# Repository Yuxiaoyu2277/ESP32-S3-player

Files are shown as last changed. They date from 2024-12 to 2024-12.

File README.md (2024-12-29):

# 时光磁带（ESP32 S3 MP3播放器）
- Description
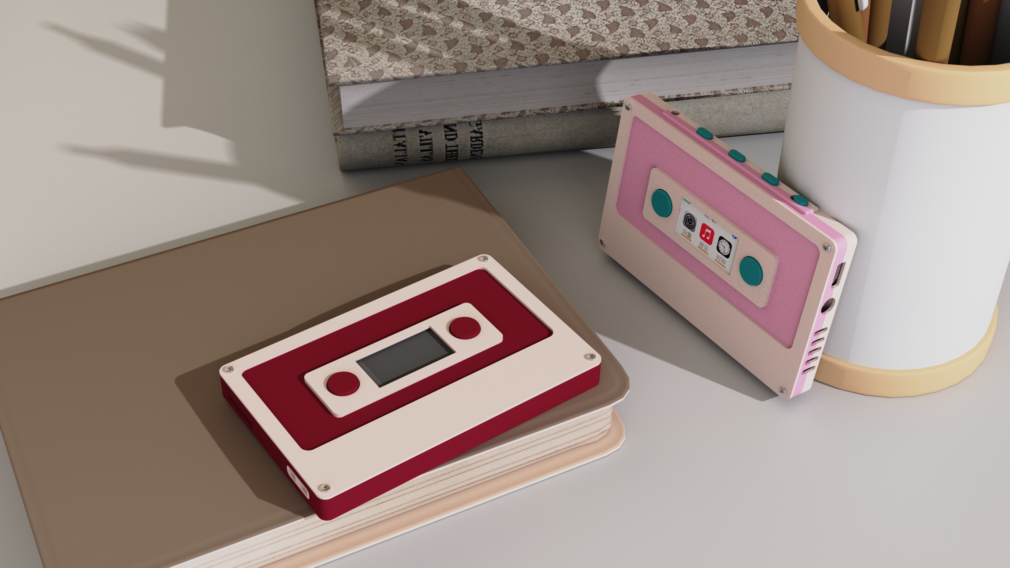
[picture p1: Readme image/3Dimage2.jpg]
- 
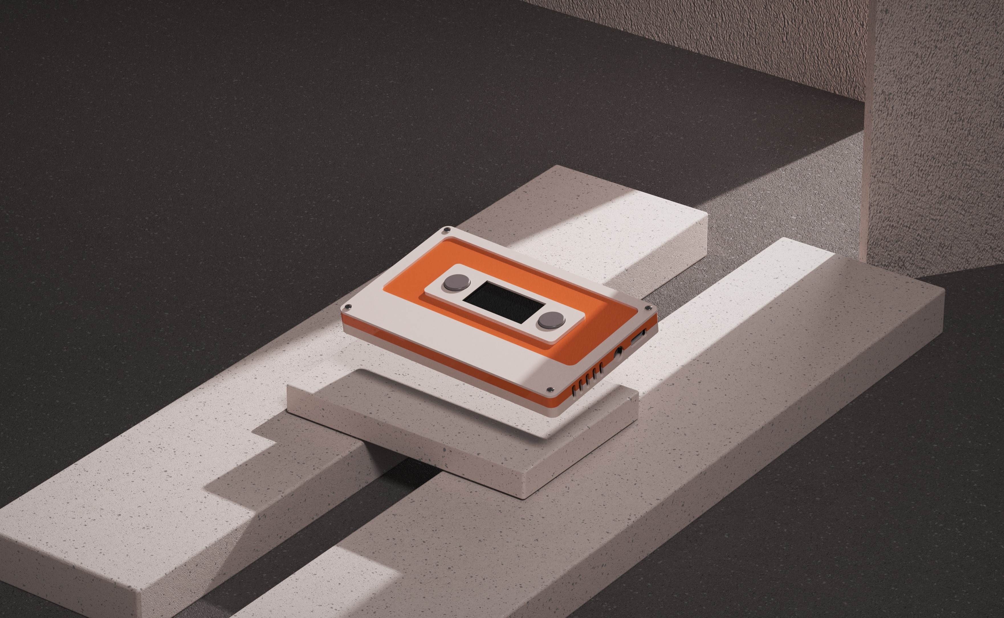
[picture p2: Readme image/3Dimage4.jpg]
- 

# [中文版](README.md) / [English Version](README.en.md)
## 目录
- [概述](#概述)
- [特性](#特性)
- [硬件型号](#硬件型号)
- [原理图](#原理图)
- [如何编译软件部分](#如何编译软件部分)
- [固件](#固件)
- [代码](#代码)
- [贡献](#贡献)
- [联系](#联系)
## 概述
本项目是一个提供硬件及软件的指南，用于构建基于ESP32 S3微控制器的MP3播放器。该设备拥有磁带复古外形的外壳，具备音乐播放、时间显示。

## 特性
该MP3播放器基于ESP32 S3微控制器，集成了2.4 GHz Wi-Fi和蓝牙5 (LE)，配备1.14英寸TFT LCD屏幕显示界面、BM8563 RTC芯片离线时间功能、WM8978 DAC高保真音频输出、NS4150B功率放大器增强音质、ETA6002充电芯片支持快速充电，同时支持USB Type-C充电和数据传输、SD/TF卡扩展存储（最高32G）、3.5mm耳机插孔以及高品质超薄扬声器，满足多样化的音乐播放需求。
## 硬件型号
- ESP32 S3：主要处理单元，集成Wi-Fi和蓝牙。
- TFT LCD（1.14英寸）：显示模块，用于用户界面。
- BM8563 RTC：实时时钟芯片，用于离线时间。
- WM8978 DAC：音频转换芯片，用于高保真声音。
- NS4150B PA：功率放大器芯片，用于音频输出。
- ETA6002 充电：锂电池充电芯片，用于锂电池充电。
- USB Type-C端口：用于充电和数据传输。
- SD/TF卡读卡器：用于存储扩展。
- 耳机插孔：3.5mm音频输出。
- 扬声器：提供音频播放。
- 按钮：具有5个按钮对UI进行交互控制。
- 开关：拥有1个开关控制电源开启关闭。

## 原理图 
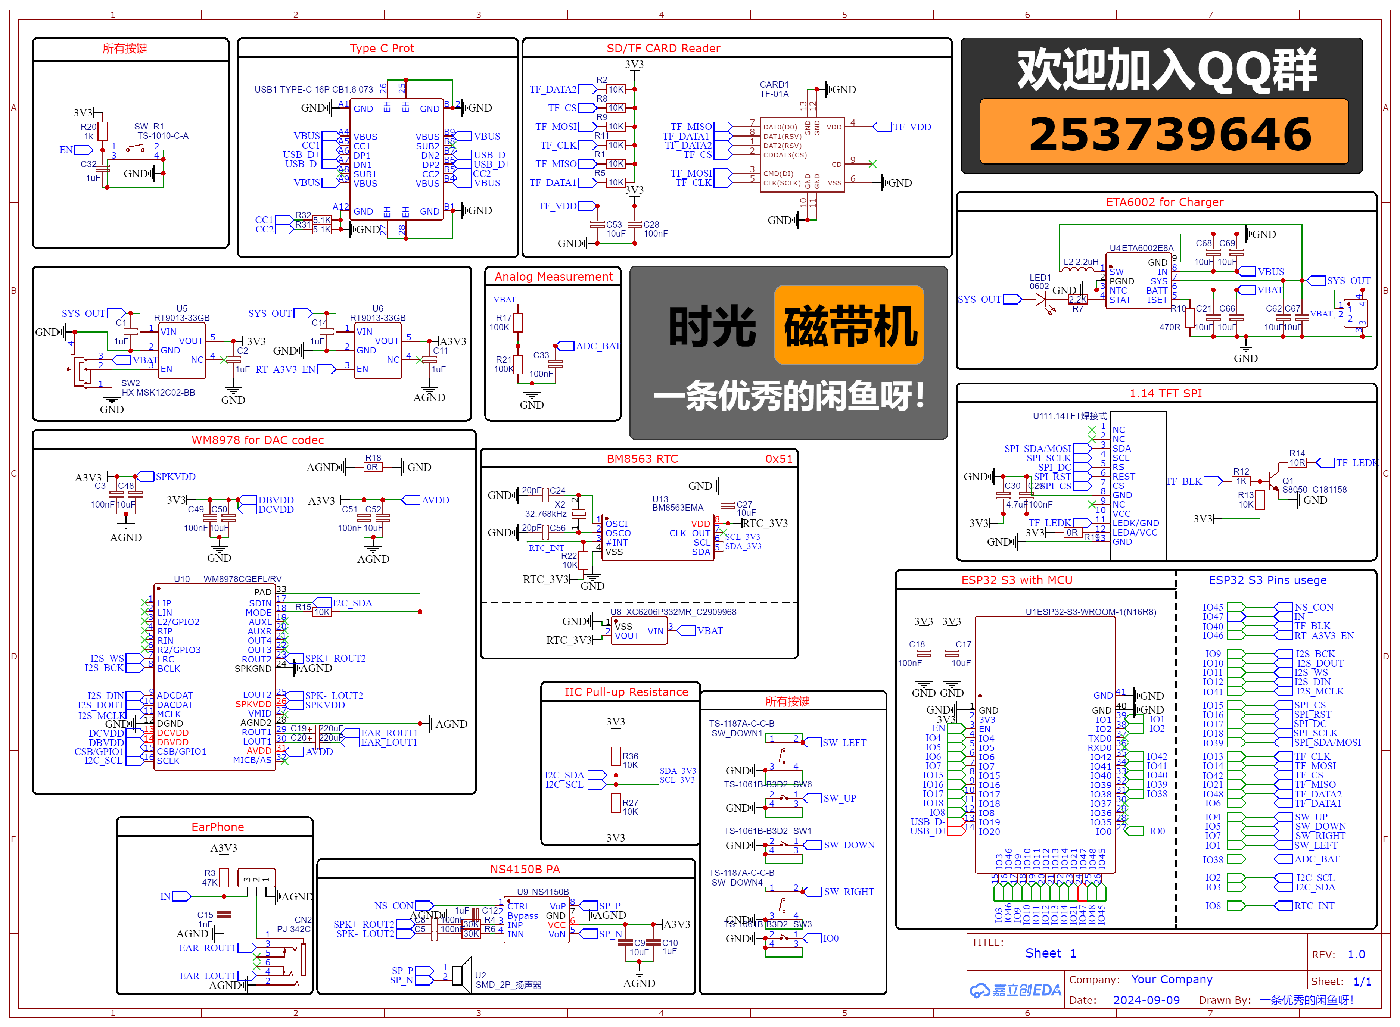
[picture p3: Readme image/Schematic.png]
- 
### 主要原理图解析
- **复位按钮**：EN引脚是ESP32 S3核心的复位引脚，采用按钮形式下拉接地该引脚可复位。按钮增加电容和电阻是为了去除电平毛刺，避免出现错误复位。
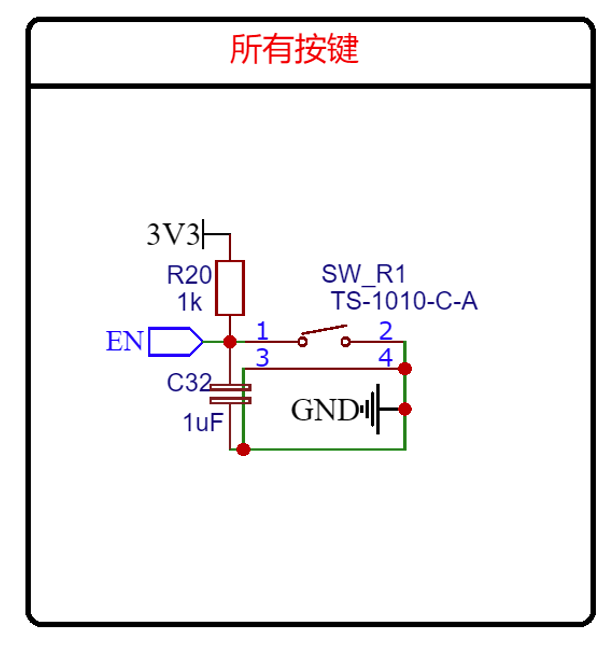
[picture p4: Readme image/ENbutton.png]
  > 
- **操作按钮**：IO_0为ESP32 S3的切换下载模式的功能按钮也可以是作为GUI操作反馈，其他按钮为GUI操作反馈。
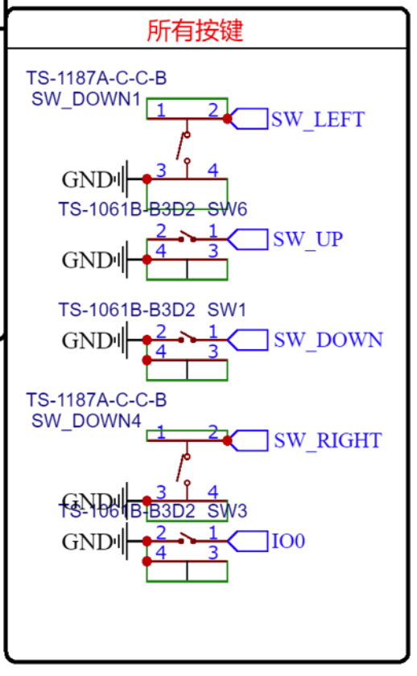
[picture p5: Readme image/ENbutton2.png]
  > 
- ESP32 S3 引脚分配表:
> 核心MCU接线说明：
> 如图所示，这是引脚的分配，核心有两个滤波电容靠近核心，是为了过滤电源线的干扰，保证核心供电稳定。其中引脚分配如下：

| **引脚编号** | **功能描述** | **备注** |
|---|---|---|
| IO45 | NS_CON | 对NS4150B的音频输出是否静音进行控制（高电平为允许声音输出）|
| IO47 | IN | 检测3.5MM耳机是否插入，如插入就是低电平 |
| IO40 | TF_BLK | 通过PWM信号进行控制屏幕亮度 |
| IO46 | RT_A3V3_EN | 音频的电压稳定芯片的开关（上拉给予3V3电压为开启） |
| IO9 | I2S_BCK | 音频接口（I2S）位时钟线 |
| IO10 | I2S_WS | 音频接口（I2S）音频左右声数据切换|
| IO11 | I2S_DOUT | 音频接口（I2S）WM8978芯片数据至ESP32 S3|
| IO12 | I2S_DIN | 音频接口（I2S）数据至WN8978芯片 |
| IO41 | I2S_MCLK | 音频接口（I2S）额外频率时钟参考线线|
| IO15 | SPI_CS | SPI接口 |
| IO16 | SPI_RST | SPI接口 |
| IO17 | SPI_DC | SPI接口 |
| IO18 | SPI_SCLK | SPI接口 |
| IO39 | SPI_SDA/MOSI | SPI接口 |
| IO13 | TF_CLK | TF卡/SD接口 |
| IO14 | TF_MOSI | TF/SD卡接口 |
| IO7 | TF_CS | TF/SD卡接口 |
| IO48 | TF_DATA2 | TF/SD卡接口 |
| IO2 | TF_DATA1 | TF/SD卡接口 |
| IO21 | SW_UP | 按键 |
| IO20 | SW_DOWN | 按键 |
| IO19 | SW_RIGHT | 按键 |
| IO8 | SW_LEFT | 按键 |
| IO0 | IO0 | 按键/切换下载模式 |
| IO4 | ADC_BAT | 电池电量检测 |
| IO2 | I2C_SCL | I2C接口 |
| IO3 | I2C_SDA | I2C接口 |
| IO8 | RTC_INT | 实时时钟中断接口 |
| IO19 | USB_D- | USB数据/type C物理接口连接 |
| IO20 | USB_D+ | USB数据/type C物理接口连接 |
- 其中仍然未用到的引脚有TXD0、RXD0原本是用于调试接口；但因为ESP32 S3支持USB日志调试，因此烧录固件可以不用单独的自动下载电路来进行烧录固件。其次关于IO37、IO36、IO35为芯片flash引脚所占用的，所以为了谨慎起见不进行使用。如果想要了解更多，请参考乐鑫官方的ESP32 S3数据手册，有你想知道的一切！
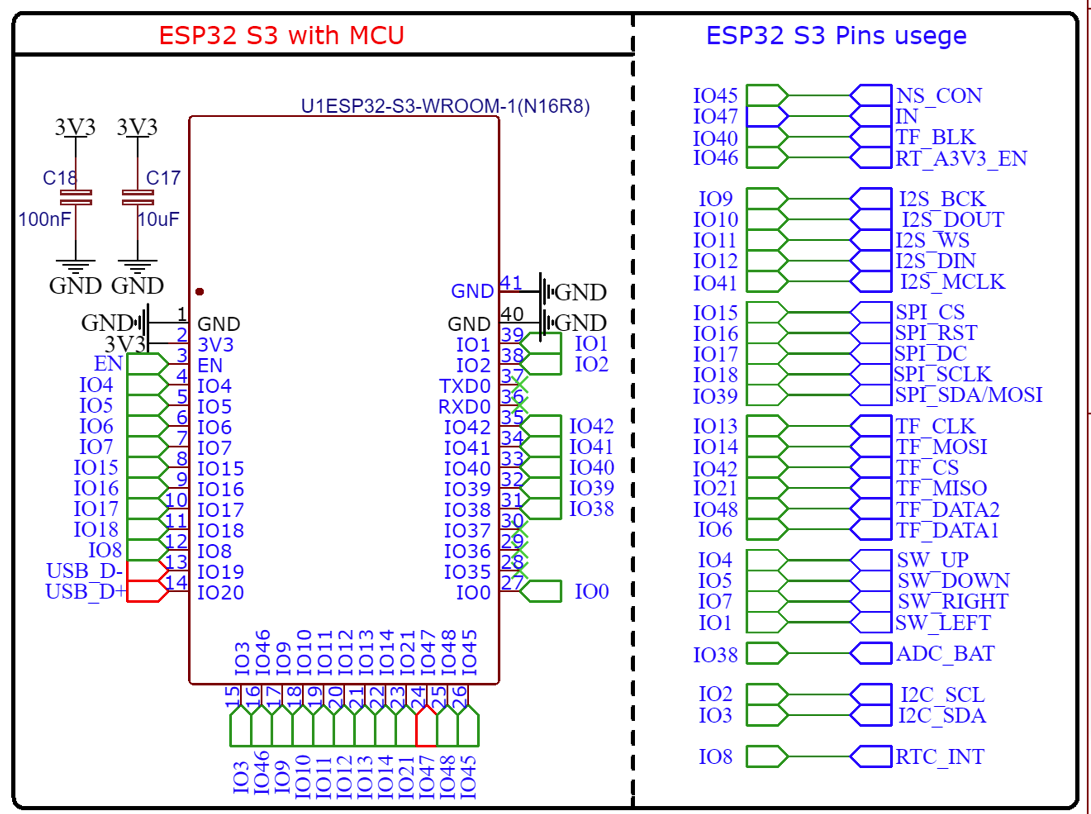
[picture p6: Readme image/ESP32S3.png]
> 
- **WM8978 DAC**: A3V3 是提供给模拟电路部分的电源。通过 C48（100nF）和 C3（10uF）电容进行滤波，3V3 为数字部分供电，通过 C49 和 C50（100nF 和 10uF）进行滤波，SPKVDD 为扬声器供电，通过 C19 和 C20（220uF）进行电源滤波。
 I2C_SCL 和 I2C_SDA 引脚（引脚 16 和 17）通过 I2C 接口控制 WM8978 的配置，EAR_LOUT1 和 EAR_ROUT1 是左右声道的耳机输出引脚，他们经过钽电容输出到耳机接口（注意建议使用钽电容，假如因为成本可以换成陶瓷电容）。SPK+ 和 SPK- 是扬声器的输出引脚，支持单声道扬声器，分别通过 AGND 接地，构成差分驱动的扬声器信号。
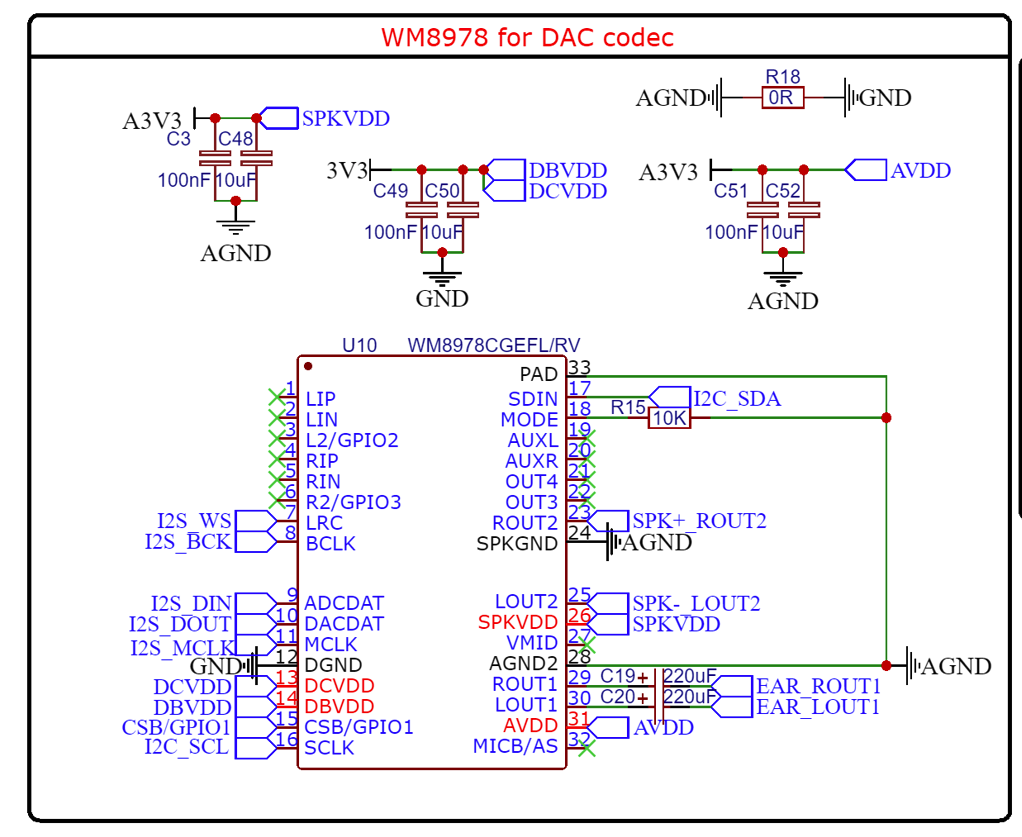
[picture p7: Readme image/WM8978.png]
> 
- **NS4150B和3.5MM**：该部分电路为音频放大器以及3.5MM接口电路，在3.5MM接口上R3、C15为滤波和限流是为了上拉该引脚的电平，当有耳机插入时耳机的线路会把引脚接地，这样就可以检测是否有耳机插入。当插入时就可以切换音频输出的模式。注意：IN检测电路部分我使用了一个切换焊盘，这个切换焊盘用于测试用途，默认需要把2-3点连接，可采用0R电阻进行连接。在NS4150B芯片上NS_CON为音频输出是否静音进行控制（高电平为允许声音输出），芯片的3号4号引脚是DAC的模拟音频输入，8号和5号是放大后的音频输出
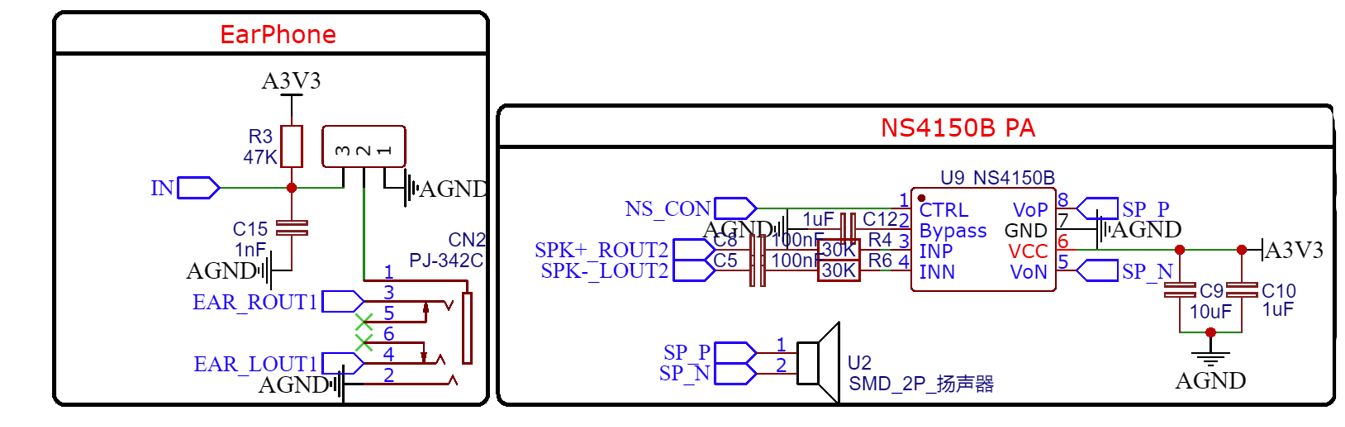
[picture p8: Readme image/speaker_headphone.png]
> 
- **BM8563**：RTC模块通过一个32.768kHz的晶振器提供时钟信号，并通过I2C接口与主控制器通信。RTC模块的电源引脚通过一个10uF的电容进行滤波，而地引脚接地。XC6206P332MR电源管理芯片负责为主RTC模块供电，它从电池（VBAT）获取电源并通过内部稳压器输出稳定的RTC_3V3电压。INT引脚为中断引脚，如果该引脚被拉低，就会触发ESP32 S3的中断，用于定时任务策略。整个设计中，多个接地电容用于稳定电源和减少噪声，确保RTC模块能在主电源断开时继续运行。
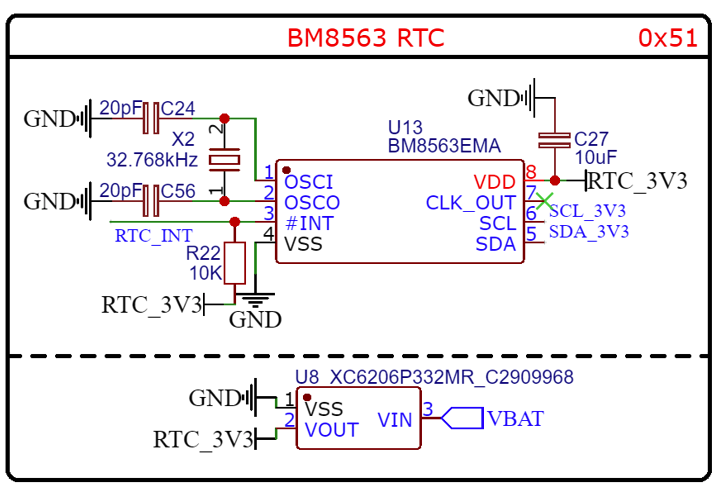
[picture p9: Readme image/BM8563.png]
> 
- **TF/SD 卡**:该电路图是一个SD/TF卡电路，通过10kΩ上拉电阻将TF_DATA2、TF_CS、TF_MOSI、TF_MISO、TF_DATA1和TF_CLK等信号线连接到3.3V电源，确保信号传输稳定。所有信号线引出后，使用者可以使用SDIO模式或者SPI模式访问储存卡。
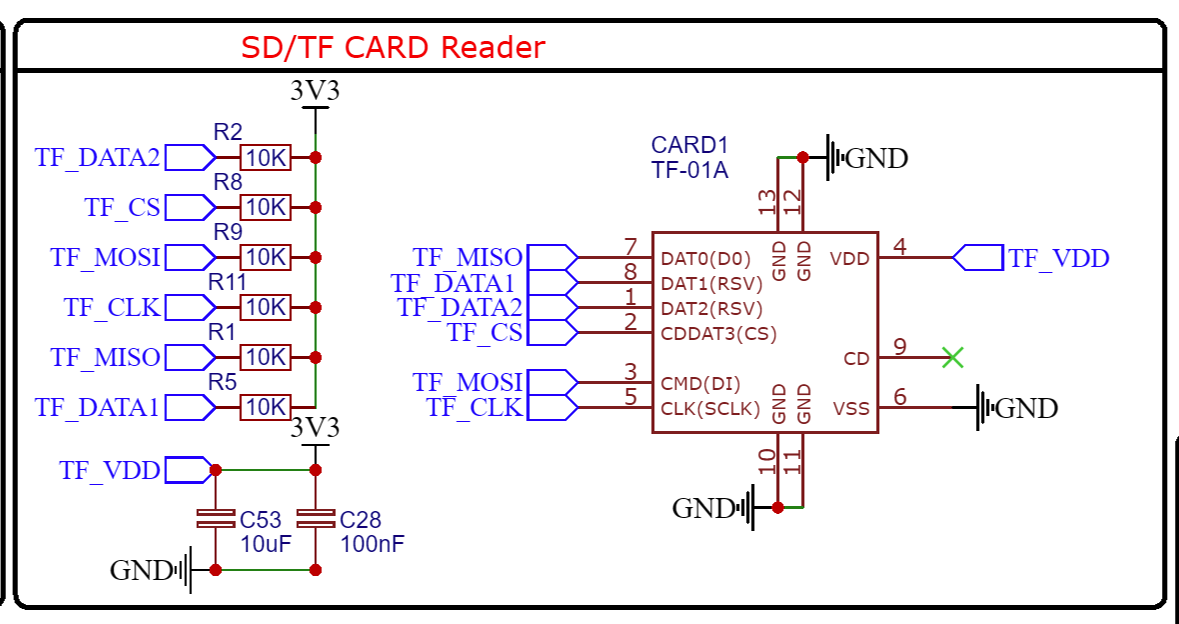
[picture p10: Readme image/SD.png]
> 
- **ETA6002**:电路通过VBUS引脚接收USB电源输入，并利用电容进行滤波和稳定。SW引脚通过2.2uH电感和2.2k电阻控制充电芯片的开关操作。VBAT引脚连接到电池正极同时VBAT会利用ADC进行监测电池电压判断电量。SYS_OUT引脚提供稳定的系统输出电压给LDO，除此之外LED和2.2k电阻指示充电状态。NTC引脚用于热管理（但因为不用所以直接接地），ISET引脚通过470电阻设置充电电流（2A）。
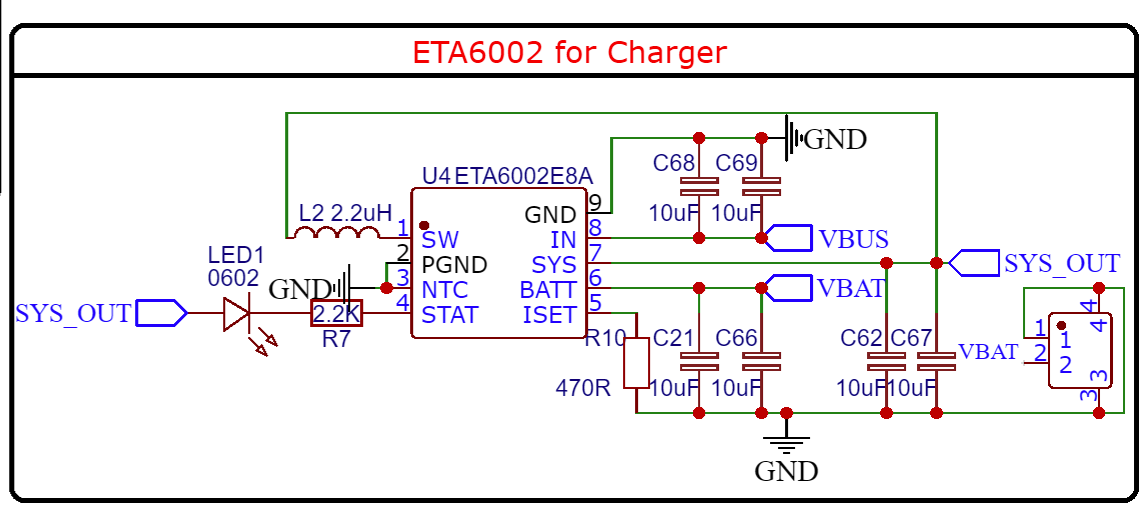
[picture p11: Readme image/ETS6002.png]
> 
## 如何开始硬件部分
- 本项目的PCB设计文件在Schematic内，里面提供了PCB的制版文件，可以通过**嘉立创**进行制作你的电路板。
- 除此之外在Schematic内提供ibom的HTML页面，方便您进行购买相关元器件。
### PCB模型预览

### 硬件部分注意事项
暂无（等候补充）
## 如何编译软件部分
- 本项目使用**Arduino IDE 2.3.4**版本进行编译，确保使用乐鑫官方的SDK版本为**2.0.14**（注意因为3.0.X版本会让工程编译产生未知的错误，为了避免请下载安装对应的SDK版本）
- 开发板的flash容量的分配16M Flash (6.25M APP/6.25MB LittleFS)，因此需要自行修改，具体修改需要对Arduino安装目录进行删除和修改文件，这里提供方法：
> 打开文件路径
```
C:\Users\（你的windows账户用户名）\AppData\Roaming\arduino-ide\Local Storage\leveldb
```
- 把关于.ldb格式文件进行删除，例如：000062.ldb（编号是随机的，你并不一定是这个文件名，只需要看文件格式进行删除）
> 打开文件路径
```
C:\Users\（你的windows账户用户名）\AppData\Local\Arduino15\packages\esp32\hardware\esp32\2.0.14
```
- 打开boards.txt文件，寻找esp32s3.menu.PartitionScheme关键字信息，并在末尾添加并保存
```boards.txt
esp32s3.menu.PartitionScheme.myMP3=MP3 16M Flash (6.25M APP/6.25MB LittleFS)
esp32s3.menu.PartitionScheme.myMP3.build.partitions=big
esp32s3.menu.PartitionScheme.myMP3.upload.maximum_size=6553600
```
> 打开文件路径
```
C:\Users\你的windows账户用户名）\AppData\Local\Arduino15\packages\esp32\hardware\esp32\2.0.14\tools\partitions
```
- 新建添加big.csv文件，并写入以下内容为flash的分区进行配置
```plaintext
# Name,   Type, SubType, Offset,  Size, Flags
nvs,      data, nvs,     0x9000,  0x5000,
otadata,  data, ota,     0xe000,  0x2000,
app0,     app,  ota_0,   0x10000, 0x640000,
app1,     app,  ota_1,   0x650000,0x640000,
spiffs,   data, spiffs,  0xc9000,0x360000,
coredump, data, coredump,0xFF0000,0x10000,
```
### 开发板配置信息

| 项目 | 详情 |
|---|---|
| 开发板 | ESP32S3 Dev Module |
| 端口 | COM4 |
| USB CDC On Boot | Enabled |
| CPU Frequency | 240MHz (WiFi) |
| Core Debug Level | None |
| USB DFU On Boot | Disabled |
| Erase All Flash Before Sketch Upload | Disabled |
| Events Run On | Core 1 |
| Flash Mode | QIO 80MHz |
| Flash Size | 16MB (128Mb) |
| JTAG Adapter | Integrated USB JTAG |
| Arduino Runs On | Core 1 |
| USB Firmware MSC On Boot | Disabled |
| Partition Scheme | MP3 16M Flash (6.25M APP/6.25MB LittleFS) |
| PSRAM | OPI PSRAM |
| Upload Mode | UART0 / Hardware CDC |
| Upload Speed | 921600 |
| USB Mode | Hardware CDC and JTAG |
| 编程器 | Esptool |

### Arduino IDE 和 SDK 版本信息

| 项目 | 详情 |
|---|---|
| Arduino IDE 版本 | 2.3.4 |
| SDK 版本 | 2.0.14 |

### 进行编译
确保编译环境一致之后，请下载GitHub本项目中的src文件夹，里面的library是所需的第三方库，这些第三方库我都进行了修改，因此和原生的第三方库都不会进行兼容。按照开源协议，我需要把自己更改的库开放出来，并注明出处。
- 打开文件路径
```text
C:\Users\（你的windows账户用户名）\Documents\Arduino\libraries
```
- 把本项目的libraries复制到你所打开本地的文件路径（注意如果本地文件路径相同名字相同的话，请在复制粘贴之前先删除本地文件路径相同的第三方库，避免造成冲突与不兼容）
- 最后请下载GitHub本项目中的ESP32_MP3_PLAYER文件夹，打开**ESP32_MP3_PLAYER.ino**，点击上传编译到板子
- 如果发生编译错误，请通过联系的联系方式告知我！使用QQ联系维护者2277236944或发送Email至Oliver.yuchunto@gmail.com
## 固件
本项目的固件是开源的，可以在本仓库的主分支中找到。为.bin格式文件，请自行google怎么直接烧录固件。
## 代码
## 贡献
欢迎贡献！如果您发现任何问题或有改进建议，请提出问题或提交拉取请求。或者直接联系我进行沟通。
## 许可证
本项目根据GNU通用公共许可证协议，只要您遵守许可证的条款，就可以自由使用、修改和分发代码，但出处必须！必须！必须！注明本项目guthub来源网址链接或注明作者：一条优秀的闲鱼呀！

## 联系
> 如有任何问题或咨询
- **推荐加入QQ群聊**：253739646
- **个人QQ**：2277236944
- **发送Email**：Oliver.yuchunto@gmail.com

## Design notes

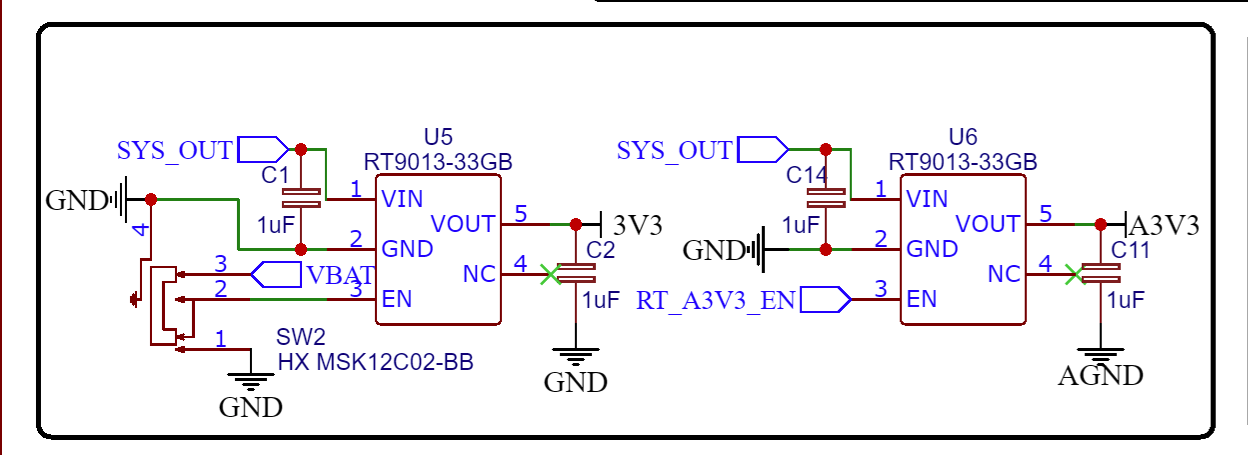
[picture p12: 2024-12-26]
Readme image/LDO.png

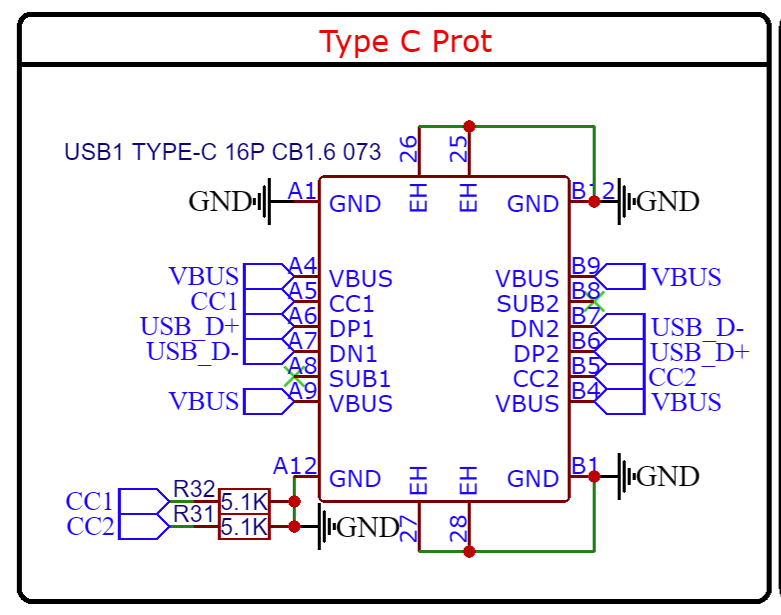
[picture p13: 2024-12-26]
Readme image/typeC.png

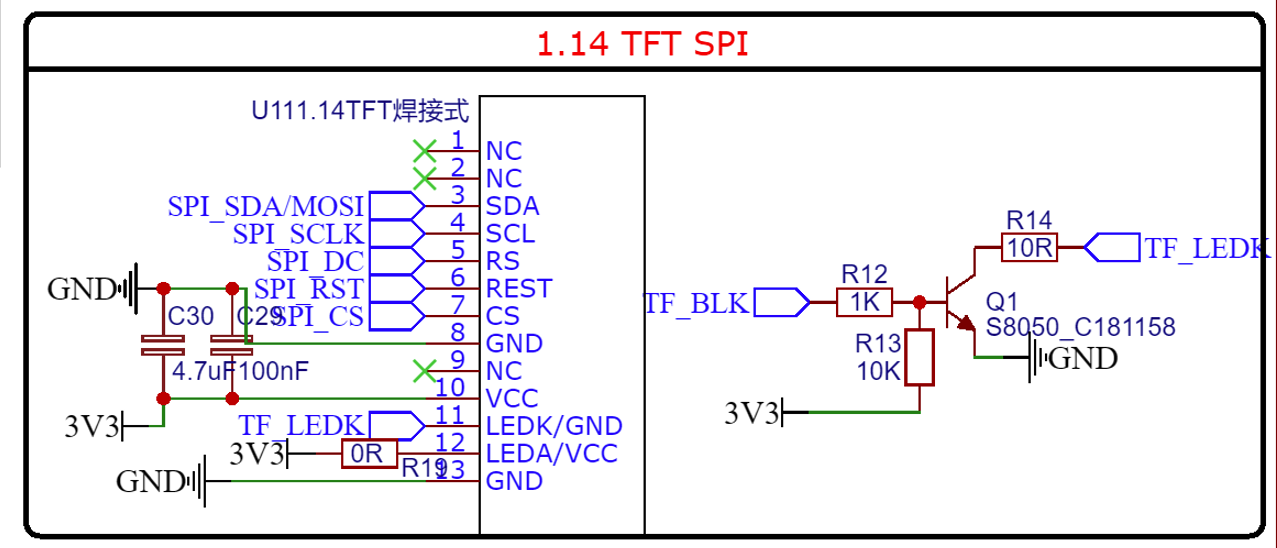
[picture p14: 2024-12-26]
Readme image/1.14.png

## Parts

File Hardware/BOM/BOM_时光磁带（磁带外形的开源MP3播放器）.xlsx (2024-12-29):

ID | Name | Designator | Footprint | Quantity
1 | 100nF | C3,C49,C51,C29,C33,C5,C8,C18,C28 | C0603 | 9
2 | 220uF | C19,C20 |  | 2
3 | 10uF | C48,C50,C52,C9,C17,C21,C53,C62,C66,C67,C68,C69,C27 | C0603 | 13
4 | 10K | R15,R1,R2,R5,R8,R9,R11 | R0603 | 7
5 | WM8978CGEFL/RV | U10 | WQFN-32_L5.0-W5.0-P0.50-TL-EP | 1
6 | NS4150B | U9 | NS4150 | 1
7 | 100K | R17 | R0603 | 1
8 | 10R | R14 | R0603 | 1
9 | 10K | R22,R27,R36,R13 | R0603 | 4
10 | TF-01A | CARD1 | TF-SMD_TF-01A | 1
11 | 4.7uF | C30 | C0603 | 1
12 | 0R | R19,R18 | C0603 | 2
13 | 100K | R21 | R0603 | 1
14 | 1uF | C1,C2,C10,C11,C12,C14,C32 | C0603 | 7
15 | 1nF | C15 | C0603 | 1
16 | 470R | R10 | C0603 | 1
17 | PJ-342C | CN2 | AUDIO-SMD_PJ-342C | 1
18 | Header-Male-2.54_1x3 | H4 | JMP-3-NO-0603 | 1
19 | 2.2uH | L2 | IND-SMD_L4.4-W4.2 | 1
20 | 0602 | LED1 | LED-SMD_L1.6-W1.0_TZ-P2-0602RTIS2-1.0T | 1
21 | S8050_C181158 | Q1 | SOT-23-3_L2.9-W1.6-P1.90-LS2.8-BR | 1
22 | 47K | R3 | R0603 | 1
23 | 30K | R4,R6 | R0603 | 2
24 | 2.2K | R7 | R0603 | 1
25 | 1k | R20 | R0603 | 1
26 | 5.1K | R31,R32 | R0603 | 2
27 | HX MSK12C02-BB | SW2 | SW-SMD_MSK12C02-HB | 1
28 | TS-1010-C-A | SW_R1 | KEY-SMD_TX-1010-X-X | 1
29 | ESP32-S3-WROOM-1(N16R8) | U1 | WIRELM-SMD_ESP32-S3-WROOM-1U-无散热孔 | 1
30 | SMD_2P_扬声器 | U2 | SMD_2P_扬声器 | 1
31 | ETA6002E8A | U4 | ESOP-8_L4.9-W3.9-P1.27-LS6.0-BL-EP-1 | 1
32 | RT9013-33GB | U5,U6 | SOT-23-5_L3.0-W1.7-P0.95-LS2.8-BL | 2
33 | TYPE-C 16P CB1.6 073 | USB1 | USB-C-SMD_SHOU_TYPE-C-16P-CB1.6 | 1
34 | TS-1061B-B3D2 | SW1,SW3,SW6 | KEY-SMD_TS-1061B-B3D2 | 3
35 | 1K | R12 | R0603 | 1
36 | 20pF | C24,C56 | C0603 | 2
37 | XC6206P332MR_C2909968 | U8 | SOT-23-3_L2.9-W1.3-P0.95-LS2.4-BR | 1
38 | 32.768kHz | X2 | CRYSTAL-SMD_L3.2-W1.5 | 1
39 | BM8563EMA | U13 | MSOP-8_L3.0-W3.0-P0.65-LS5.0-BL | 1
40 | 1.14TFT焊接式 | U11 | 1.14TFT焊接式B | 1
41 | TS-1187A-C-C-B | SW_DOWN1,SW_DOWN4 | SW-SMD_4P-L5.1-W5.1-P3.70-LS6.5-TL-2 | 2

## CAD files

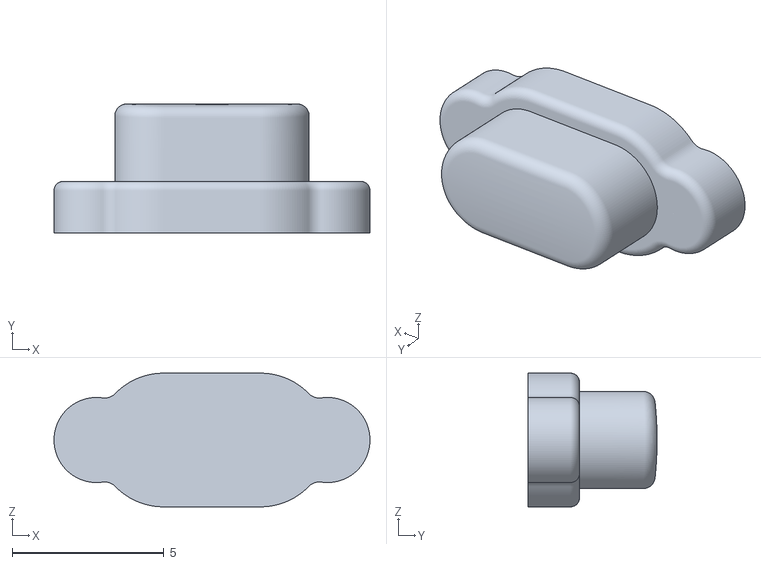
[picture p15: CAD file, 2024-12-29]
Modles/上侧边按钮1.stl
10.4 x 4.25 x 4.40

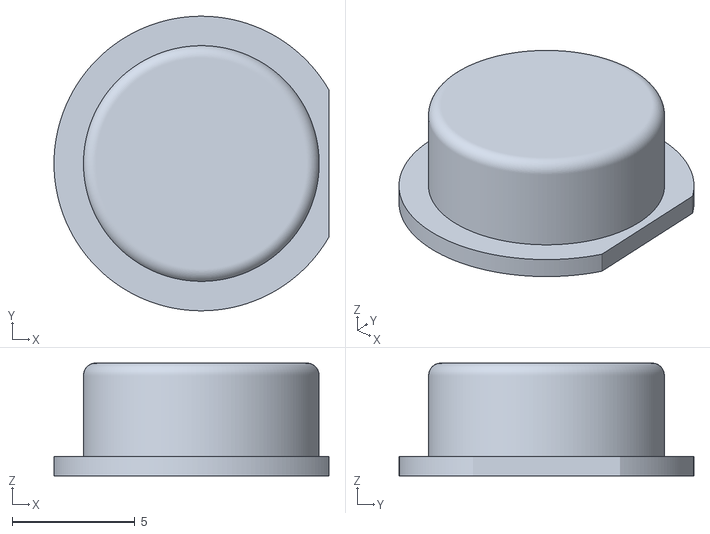
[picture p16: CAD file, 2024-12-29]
Modles/左边按钮.stl
11.2 x 12.0 x 4.60

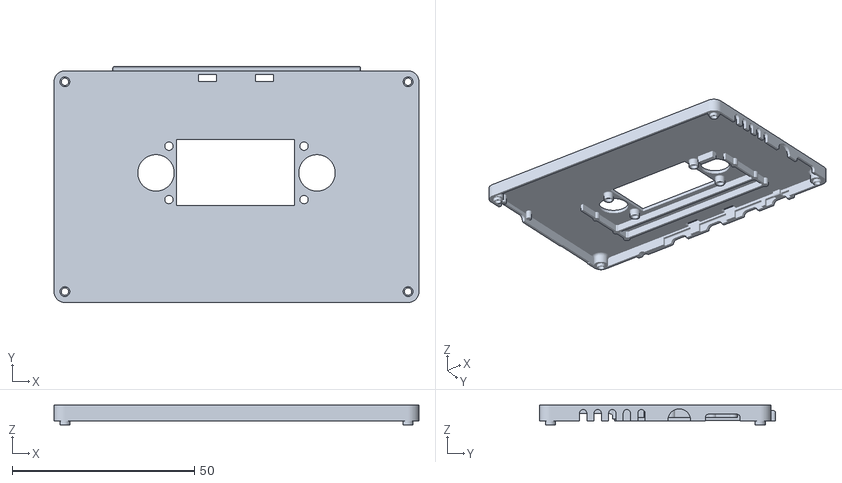
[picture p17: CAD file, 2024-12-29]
Modles/上壳.stl
100.2 x 64.8 x 5.40

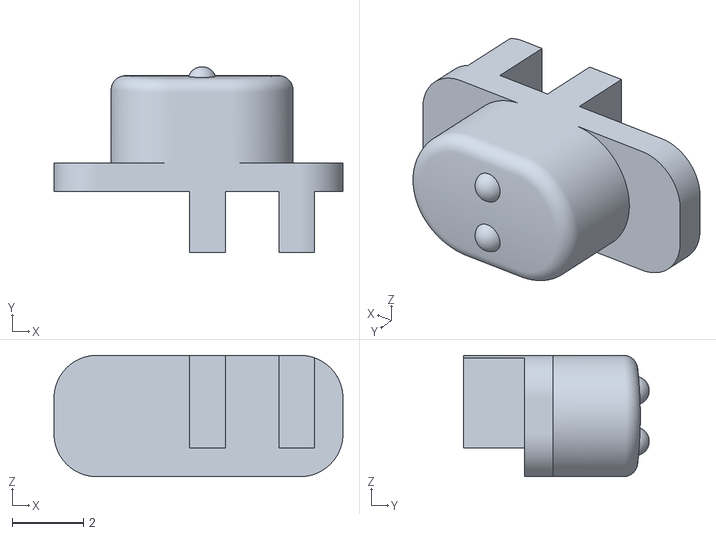
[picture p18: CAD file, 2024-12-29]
Modles/开关.stl
8.10 x 5.20 x 3.40

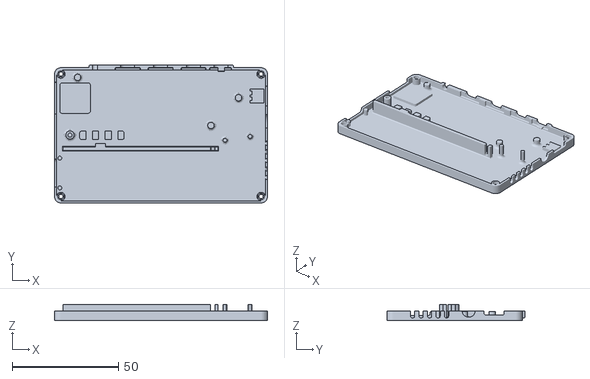
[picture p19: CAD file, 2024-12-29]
Modles/下壳.stl
100.2 x 64.8 x 7.60

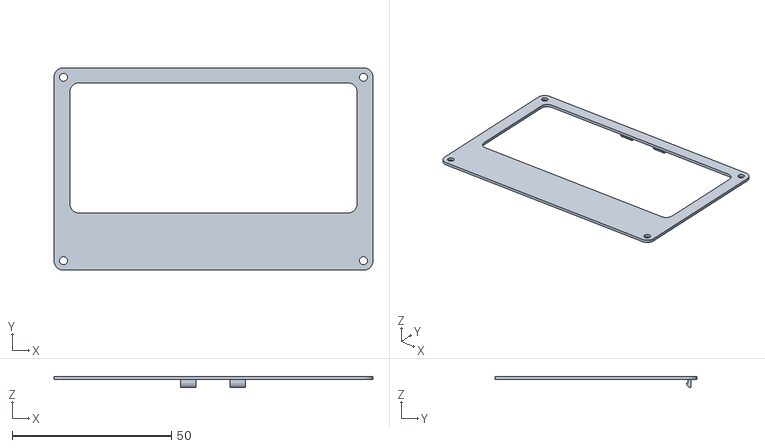
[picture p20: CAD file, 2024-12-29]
Modles/盖板2.stl
100.2 x 63.6 x 3.49

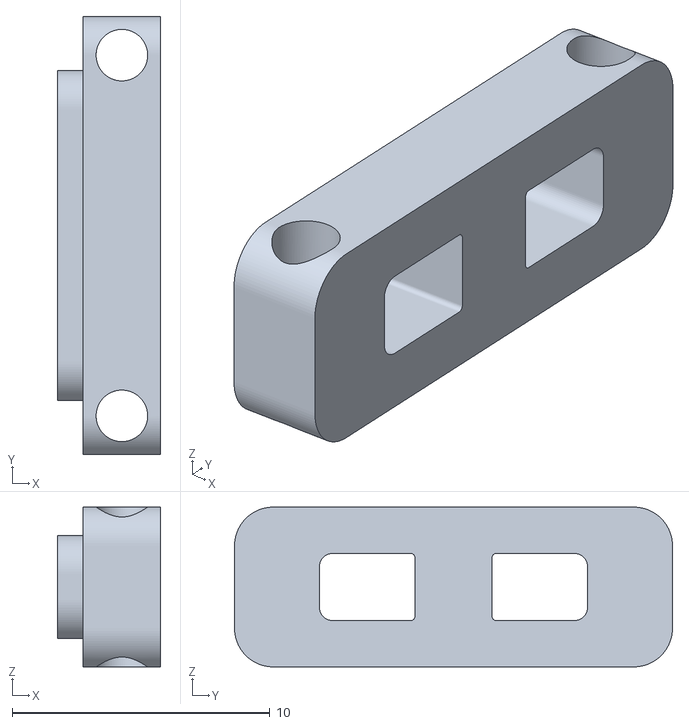
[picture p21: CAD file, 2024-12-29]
Modles/挂绳孔.stl
4.00 x 17.0 x 6.20

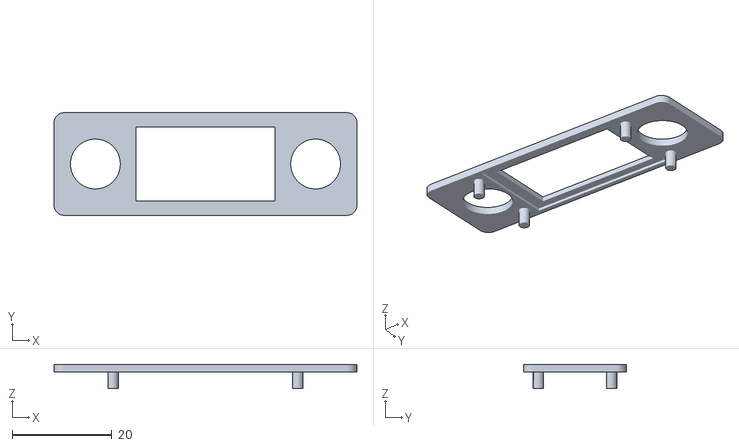
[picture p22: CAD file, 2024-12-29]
Modles/盖板.stl
60.8 x 20.6 x 4.91

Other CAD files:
Modles/右边按钮.stl

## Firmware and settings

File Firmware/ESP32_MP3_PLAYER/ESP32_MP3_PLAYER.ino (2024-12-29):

#include <Arduino.h>
#include <TFT_eSPI.h>
#include <U8g2_for_TFT_eSPI.h>
#include <SPI.h>
#include <SD.h>
#include <WM8978.h>
#include <Audio.h>
#include <Button2.h>
#include <vector>
#include "background.h"  //背景图
#include "music_icon.h"  //音乐图标
#include <freertos/FreeRTOS.h>
#include <freertos/task.h>
#include <esp_log.h>
// 按钮引脚定义
#define SW_MENU 0
#define SW_CONF 4
#define SW_BACK 5
#define SW_RIGHT 1
#define SW_LEFT 7
#define TFT_BCK 40  // 屏幕背光控制引脚

// SD卡引脚定义
#define TF_CLK 13
#define TF_CMD 14
#define TF_CS 42
#define TF_DATA0 21
#define TF_DATA1 6
#define TF_DATA2 48

// IIS初始化引脚定义
#define I2S_DOUT 10
#define I2S_BCLK 9
#define I2S_WS 11
#define I2S_MCLKPIN 41
#define I2S_DIN 12

// IIC引脚定义
#define I2C_SDA 3
#define I2C_SCL 2

#define NS_CON 45
#define RT_A3V3_EN 46

// 创建 TFT 屏幕对象和精灵对象
TFT_eSPI tft = TFT_eSPI(135, 240);
TFT_eSprite sprite = TFT_eSprite(&tft);
U8g2_for_TFT_eSPI u8g2;
Audio audio;
WM8978 dac;
Button2 button;

// 创建Button2对象
Button2 buttonLeft(SW_LEFT);
Button2 buttonRight(SW_RIGHT);
Button2 buttonConf(SW_CONF);
Button2 buttonBack(SW_BACK);

int counter = 0;  // 初始计数值为0

int cursorX = 23;      // 初始光标X坐标
int cursorY = 124;     // 光标的Y坐标固定为124
int cursorWidth = 47;  // 光标宽度
int cursorHeight = 4;  // 光标高度

int targetX = 23;        // 目标光标X坐标
int speed = 4;           // 光标的移动速度
int step_increment = 1;  // 步长增量，用于加速光标移动

// 定义应用状态
enum AppState {
  MAIN_MENU,
  MUSIC_APP
};

AppState currentState = MAIN_MENU;

// 定义音乐应用的状态
enum MusicAppState {
  MUSIC_FILES,    // 音乐文件列表状态
  MUSIC_PLAYBACK  // 音乐播放状态（暂时留空）
};
MusicAppState currentMusicAppState = MUSIC_FILES;  // 初始化为 MUSIC_FILES 状态

TaskHandle_t audioTaskHandle = NULL;  // 用于存储音频任务的句柄


std::vector<String> listFilesInDirectory(const char* directory) {
  std::vector<String> fileNames;  // 用于存储文件名的列表

  File dir = SD.open(directory);  // 打开指定目录
  if (!dir) {
    Serial.println("Failed to open directory!");
    return fileNames;  // 如果目录打不开，返回空列表
  }

  // 遍历目录中的所有文件
  while (true) {
    File entry = dir.openNextFile();
    if (!entry) {
      break;  // 如果没有更多文件，退出循环
    }

    if (!entry.isDirectory()) {
      fileNames.push_back(entry.name());  // 如果是文件，加入文件名列表
    }
    entry.close();  // 关闭文件
  }

  dir.close();       // 关闭目录
  return fileNames;  // 返回文件名列表
}
// 更新计数器函数
void updateCounter() {
  buttonLeft.loop();
  buttonRight.loop();
  if (buttonLeft.isPressed()) {  // 左按钮按下，减少
    counter--;
    if (counter < 0) {
      counter = 2;  // 如果小于0，变为2
    }
    delay(200);  // 防止按钮抖动，增加延迟
  }

  if (buttonRight.isPressed()) {  // 右按钮按下，增加
    counter++;
    if (counter > 2) {
      counter = 0;  // 如果大于2，变为0
    }
    delay(200);  // 防止按钮抖动，增加延迟
  }
}
// 横向或纵向平滑移动的动画函数
// 参数：current_pos 当前坐标, target_pos 目标坐标, speed 移动速度
// 返回：动画是否完成（true: 完成，false: 未完成）
bool animateMovement(int& current_pos, int target_pos, int& speed, int step_increment) {
  if (current_pos == target_pos)
    return true;
  int step = (target_pos - current_pos) > 0 ? speed : -speed;
  current_pos += step;
  if ((step > 0 && current_pos > target_pos) || (step < 0 && current_pos < target_pos)) {
    current_pos = target_pos;
  }
  speed += step_increment;
  return false;  // 动画仍在进行中
}
void displayVerticalList(const std::vector<String>& list, int startX, int startY, int lineHeight, int spacing, int selectedIndex) {
  const int itemsPerPage = 5;                                                         // 每页最多显示的项目数
  int currentPage = selectedIndex / itemsPerPage;                                     // 当前页码
  int totalPages = (list.size() + itemsPerPage - 1) / itemsPerPage;                   // 总页数
  int startIndex = currentPage * itemsPerPage;                                        // 当前页的起始索引
  int endIndex = std::min(startIndex + itemsPerPage, static_cast<int>(list.size()));  // 当前页的结束索引
  static unsigned long lastScrollTime = 0;                                            // 滚动的时间控制
  static int scrollSpeed = 1;                                                         // 滚动的速度
  static int scrollStepIncrement = 1;                                                 // 滚动的步长增量
  static int scrollOffset = 0;                                                        // 滚动的偏移量
  static int lastSelectedIndex = -1;                                                  // 记录上一次选中的索引
  // 检查是否需要重置滚动状态
  if (selectedIndex != lastSelectedIndex) {
    scrollOffset = 0;                   // 重置滚动偏移量
    lastScrollTime = 0;                 // 重置滚动计时
    scrollSpeed = 1;                    // 重置滚动速度
    lastSelectedIndex = selectedIndex;  // 更新选中的索引
  }
  sprite.fillSprite(TFT_WHITE);  // 清空背景
  int yPosition = startY;        // 起始Y坐标
  // 遍历当前页的项目
  for (int i = startIndex; i < endIndex; i++) {
    String text = list[i];
    int textWidth = u8g2.getUTF8Width(text.c_str());  // 获取文字宽度
    // 如果是当前选中的项，绘制高亮背景
    if (i == selectedIndex) {
      sprite.fillRoundRect(startX - 5, yPosition - (lineHeight / 2), 220, lineHeight, 8, TFT_ORANGE);  // 长圆矩形背景
    } else {
      sprite.fillRoundRect(startX - 5, yPosition - (lineHeight / 2), 220, lineHeight, 8, TFT_LIGHTGREY);  // 普通背景
    }
    // 如果文字过长且当前项被选中，处理滚动显示
    if (textWidth > 200 && i == selectedIndex) {  // 假设显示区域最大宽度为 200
      // 每 300ms 滚动一次
      if (millis() - lastScrollTime > 400) {
        int targetScrollOffset = textWidth - 200;  // 目标滚动偏移量
        if (animateMovement(scrollOffset, targetScrollOffset, scrollSpeed, scrollStepIncrement)) {
          // 当滚动到达目标位置时，重置滚动参数
          scrollOffset = 0;
          scrollSpeed = 1;
        }
        lastScrollTime = millis();
      }
      // 计算文字的显示起始位置
      int textX = startX - scrollOffset;
      if (textX + textWidth > startX) {
        u8g2.setCursor(textX, yPosition + (lineHeight / 4));  // 设置文字位置
        u8g2.print(text);                                     // 打印文字
      }
    } else {
      // 如果文字宽度小于显示区域或当前项未被选中，正常显示
      u8g2.setCursor(startX, yPosition + (lineHeight / 4));  // 设置文字位置
      u8g2.print(text);                                      // 打印文字
    }
    yPosition += lineHeight + spacing;  // 更新Y坐标，增加间距
  }
  // 显示页码信息
  String pageInfo = "Page " + String(currentPage + 1) + " / " + String(totalPages);
  u8g2.setCursor(45, 135);  // 设置页码显示位置
  u8g2.print(pageInfo);

  sprite.pushSprite(0, 0);  // 更新显示
}
String formatTime(uint32_t seconds) {
  int minutes = seconds / 60;
  int remainingSeconds = seconds % 60;
  String formattedTime = String(minutes) + ":" + (remainingSeconds < 10 ? "0" : "") + String(remainingSeconds);
  return formattedTime;
}
// 音频处理任务
void audioTask(void* pvParameters) {
  TickType_t xLastWakeTime = xTaskGetTickCount();
  const TickType_t xFrequency = pdMS_TO_TICKS(1);  // 每毫秒唤醒一次

  while (true) {
    audio.loop();
    vTaskDelayUntil(&xLastWakeTime, xFrequency);
  }
}
void setup() {
  Serial.begin(115200);
  pinMode(TF_CS, OUTPUT);
  digitalWrite(TF_CS, HIGH);
  SPI.begin(TF_CLK, TF_DATA0, TF_CMD);
  SPI.setFrequency(8000000);
  if (!SD.begin(TF_CS)) {
    Serial.println("SD Card initialization failed!");
  } else {
    Serial.println("SD Card initialized.");
  }
  pinMode(NS_CON, OUTPUT);
  pinMode(RT_A3V3_EN, OUTPUT);
  digitalWrite(NS_CON, HIGH);
  digitalWrite(RT_A3V3_EN, HIGH);
  dac.begin(I2C_SDA, I2C_SCL);
  audio.setPinout(I2S_BCLK, I2S_WS, I2S_DOUT, I2S_DIN, I2S_MCLKPIN);
  dac.setSPKvol(55);
  dac.setHPvol(0, 0);

  tft.init();
  tft.setRotation(3);  // 屏幕设置
  u8g2.begin(tft);
  u8g2.setDisplay(&sprite);
  xTaskCreatePinnedToCore(audioTask, "AudioTask", 4096, NULL, 1, NULL, 0);
}
void loop() {
  audio.loop();  // 启动音频播放循环
  switch (currentState) {
    case MAIN_MENU:
      main_menu();
      break;
    case MUSIC_APP:
      music_app();
      break;
  }
}
// 主菜单显示函数
void main_menu() {
  updateCounter();  // 更新计数器
  sprite.createSprite(240, 135);
  sprite.fillSprite(TFT_WHITE);  // 清空屏幕
  sprite.pushImage(0, 0, MIANBACKGROUND_WIDTH, MIANBACKGROUND_HEIGHT, mianbackground);
  // 更新目标光标位置
  if (counter == 0) {
    targetX = 23;  // 选项 0
  } else if (counter == 1) {
    targetX = 97;  // 选项 1
  } else if (counter == 2) {
    targetX = 171;  // 选项 2
  }
  // 使用 animateMovement 平滑移动光标
  if (animateMovement(cursorX, targetX, speed, step_increment)) {
    // 当光标到达目标位置时，动画完成
  }
  sprite.fillRect(cursorX, cursorY, cursorWidth, cursorHeight, TFT_ORANGE);  // 绘制橙色光标
  sprite.pushSprite(0, 0);                                                   // 更新显示
  // 检测确认按钮按下且counter ==1时，切换到music_app
  buttonConf.loop();
  if (counter == 1 && buttonConf.isPressed()) {
    currentState = MUSIC_APP;
    delay(200);  // 防抖
  }
}
void music_app() {
  static int selectedIndex = 0;        // 当前选中的项索引
  static bool hasListedFiles = false;  // 标记是否已经列出文件
  static std::vector<String> files;    // 文件列表
  static bool isPlaying = false;       // 播放状态
  static uint32_t lastUpdateTime = 0;  // 上次更新时间

  switch (currentMusicAppState) {
    case MUSIC_FILES:
      {
        // 检测返回按钮按下，返回主菜单
        buttonLeft.loop();
        buttonRight.loop();
        buttonConf.loop();
        buttonBack.loop();  // 检测返回按钮
        if (buttonBack.isPressed()) {
          currentState = MAIN_MENU;  // 切换到主菜单状态
          delay(200);                // 防抖延迟
          return;                    // 跳出 music_app()，直接返回主菜单
        }
        if (!hasListedFiles) {
          const char* folder = "/music";         // 指定目录
          files = listFilesInDirectory(folder);  // 获取文件列表

          Serial.println("Music Files:");
          for (size_t i = 0; i < files.size(); i++) {
            Serial.println(files[i]);  // 打印文件名到串口
          }
          hasListedFiles = true;  // 文件列表只获取一次
        }
        // 检测按钮输入，更新 selectedIndex
        if (buttonLeft.isPressed()) {
          selectedIndex--;
          if (selectedIndex < 0) {
            selectedIndex = files.size() - 1;  // 循环到最后一个
          }
          delay(200);  // 防抖延迟
        }
        if (buttonRight.isPressed()) {
          selectedIndex++;
          if (selectedIndex >= files.size()) {
            selectedIndex = 0;  // 循环到第一个
          }
          delay(200);  // 防抖延迟
        }
        // 检测确认按钮按下，切换到 MUSIC_PLAYBACK
        if (buttonConf.isPressed()) {
          currentMusicAppState = MUSIC_PLAYBACK;
          audio.connecttoFS(SD, ("/music/" + files[selectedIndex]).c_str());
          isPlaying = true;
          lastUpdateTime = millis();
          delay(200);

          // 创建音频处理任务
          if (audioTaskHandle == NULL) {
            xTaskCreatePinnedToCore(audioTask, "AudioTask", 4096, NULL, 1, &audioTaskHandle, 0);
          }
        }

        // 显示文件列表到屏幕
        sprite.createSprite(240, 135);
        sprite.fillSprite(TFT_WHITE);  // 清空屏幕
        u8g2.setFont(all_font);        // 设置自定义字体
        u8g2.setFontMode(1);           // 设置字体透明背景
        u8g2.setForegroundColor(0x0000);
        // 使用 displayVerticalList 显示文件列表
        int startX = 10;
        int startY = 20;
        int lineHeight = 20;
        int spacing = 2.5;  // 设置选项间距为 5 像素
        displayVerticalList(files, startX, startY, lineHeight, spacing, selectedIndex);

        sprite.pushSprite(0, 0);  // 更新显示
        break;
      }
    case MUSIC_PLAYBACK:
      {
        buttonLeft.loop();
        buttonRight.loop();
        buttonConf.loop();
        buttonBack.loop();  // 检测返回按钮
        if (buttonBack.isPressed()) {
          currentMusicAppState = MUSIC_FILES;
          audio.stopSong();  // 停止播放
          delay(200);

          // 删除音频处理任务
          if (audioTaskHandle != NULL) {
            vTaskDelete(audioTaskHandle);
            audioTaskHandle = NULL;
          }
        }
        // 检测确认按钮按下，切换播放/暂停状态
        if (buttonConf.isPressed()) {
          isPlaying = !isPlaying;  // 切换播放状态
          audio.pauseResume();     // 切换播放/暂停
          delay(200);  // 防抖延迟
        }
        // 获取歌曲文件名、总时间和当前播放时间
        String currentSong = files[selectedIndex];              // 获取当前播放的歌曲名
        uint32_t totalDuration = audio.getAudioFileDuration();  // 获取音频文件的总时长
        uint32_t currentTime = audio.getAudioCurrentTime();     // 获取当前播放时间

        // 格式化总时间和当前时间
        String totalTime = formatTime(totalDuration);
        String currentPlayingTime = formatTime(currentTime);

        // 显示播放界面
        sprite.createSprite(240, 135);
        sprite.fillSprite(TFT_WHITE);
        u8g2.setFont(all_font);
        u8g2.setFontMode(1);
        u8g2.setForegroundColor(0x0000);
        sprite.pushImage(0, 0, MUSICBACKGROUND_WIDTH, MUSICBACKGROUND_HEIGHT, musicbackground);  // 绘制音乐界面背景图
        // 显示 "播放中：" 或 "暂停中：" 文本
        if (isPlaying) {
          u8g2.setCursor(20, 50);
          u8g2.print("播放中：");
          sprite.pushImage(96, 87, CONTROL_PLAY_WIDTH, CONTROL_PLAY_HEIGHT, control_play);  // 绘制播放图标
        } else {
          u8g2.setCursor(20, 50);
          u8g2.print("暂停中：");
          sprite.pushImage(96, 87, CONTROL_STOP_WIDTH, CONTROL_STOP_HEIGHT, control_stop);  // 绘制暂停图标
        }
        // 显示歌曲名称
        u8g2.setCursor(87, 50);
        u8g2.print(currentSong);

        // 显示总时间
        u8g2.setCursor(185, 98);
        u8g2.print(totalTime);  // 显示总时间

        // 显示当前播放时间
        u8g2.setCursor(0, 98);
        u8g2.print(currentPlayingTime);  // 显示当前时间

        sprite.pushSprite(0, 0);  // 更新显示
        break;
      }
  }
}

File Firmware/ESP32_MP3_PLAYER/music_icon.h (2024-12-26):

#define CONTROL_STOP_HEIGHT 48
#define CONTROL_STOP_WIDTH 48

// array size is 4608
static const uint16_t control_stop[] PROGMEM  = {
  0xffff, 0xffff, 0xffff, 0xffff, 0xffff, 0xffff, 0xffff, 0xffff, 0xffff, 0xffff, 0xffff, 0xffff, 0xffff, 0xffff, 0xffff, 0xffff, 0xffff, 0xffff, 0xffff, 0xffff, 0xffff, 0xffff, 0xffff, 0xffff, 0xffff, 0xffff, 0xffff, 0xffff, 0xffff, 0xffff, 0xffff, 0xffff, 0xffff, 0xffff, 0xffff, 0xffff, 0xffff, 0xffff, 0xffff, 0xffff, 0xffff, 0xffff, 0xffff, 0xffff, 0xffff, 0xffff, 0xffff, 0xffff, 
  0xffff, 0xffff, 0xffff, 0xffff, 0xffff, 0xffff, 0xffff, 0xffff, 0xffff, 0xffff, 0xffff, 0xffff, 0xffff, 0xffff, 0xffff, 0xffff, 0xffff, 0xffff, 0xffff, 0xffff, 0xffff, 0xffff, 0xffff, 0xffff, 0xffff, 0xffff, 0xffff, 0xffff, 0xffff, 0xffff, 0xffff, 0xffff, 0xffff, 0xffff, 0xffff, 0xffff, 0xffff, 0xffff, 0xffff, 0xffff, 0xffff, 0xffff, 0xffff, 0xffff, 0xffff, 0xffff, 0xffff, 0xffff, 
  0xffff, 0xffff, 0xffff, 0xffff, 0xffff, 0xffff, 0xffff, 0xffff, 0xffff, 0xffff, 0xffff, 0xffff, 0xffff, 0xffff, 0xffff, 0xffff, 0xffff, 0xffff, 0xffff, 0xffff, 0xffff, 0xffff, 0xffff, 0xffff, 0xffff, 0xffff, 0xffff, 0xffff, 0xffff, 0xffff, 0xffff, 0xffff, 0xffff, 0xffff, 0xffff, 0xffff, 0xffff, 0xffff, 0xffff, 0xffff, 0xffff, 0xffff, 0xffff, 0xffff, 0xffff, 0xffff, 0xffff, 0xffff, 
  0xffff, 0xffff, 0xffff, 0xffff, 0xffff, 0xffff, 0xffff, 0xffff, 0xffff, 0xffff, 0xffff, 0xffff, 0xffff, 0xffff, 0xffff, 0xffff, 0xffff, 0xffff, 0xdfff, 0x9ef7, 0x3ce7, 0xdbde, 0x9ad6, 0x59ce, 0x79ce, 0x9ad6, 0xdbde, 0x3ce7, 0x9ef7, 0xdfff, 0xffff, 0xffff, 0xffff, 0xffff, 0xffff, 0xffff, 0xffff, 0xffff, 0xffff, 0xffff, 0xffff, 0xffff, 0xffff, 0xffff, 0xffff, 0xffff, 0xffff, 0xffff, 
  0xffff, 0xffff, 0xffff, 0xffff, 0xffff, 0xffff, 0xffff, 0xffff, 0xffff, 0xffff, 0xffff, 0xffff, 0xffff, 0xffff, 0xffff, 0x9ef7, 0x38c6, 0x3084, 0x494a, 0x6529, 0x0421, 0xe318, 0xe318, 0xe318, 0xe318, 0xe318, 0xe318, 0x0421, 0x6529, 0x694a, 0x3084, 0x38c6, 0x9ef7, 0xffff, 0xffff, 0xffff, 0xffff, 0xffff, 0xffff, 0xffff, 0xffff, 0xffff, 0xffff, 0xffff, 0xffff, 0xffff, 0xffff, 0xffff, 
  0xffff, 0xffff, 0xffff, 0xffff, 0xffff, 0xffff, 0xffff, 0xffff, 0xffff, 0xffff, 0xffff, 0xffff, 0xdfff, 0xdbde, 0xae73, 0x8210, 0x0000, 0x0000, 0x0000, 0x0000, 0x0000, 0x0000, 0x0000, 0x0000, 0x0000, 0x0000, 0x0000, 0x0000, 0x0000, 0x0000, 0x0000, 0x0000, 0x8210, 0xcf7b, 0xdbde, 0xdfff, 0xffff, 0xffff, 0xffff, 0xffff, 0xffff, 0xffff, 0xffff, 0xffff, 0xffff, 0xffff, 0xffff, 0xffff, 
  0xffff, 0xffff, 0xffff, 0xffff, 0xffff, 0xffff, 0xffff, 0xffff, 0xffff, 0xffff, 0xdfff, 0x79ce, 0x8e73, 0x8210, 0x0000, 0x0000, 0x0000, 0x0000, 0x0000, 0x0000, 0x0000, 0x0000, 0x0000, 0x0000, 0x0000, 0x0000, 0x0000, 0x0000, 0x0000, 0x0000, 0x0000, 0x0000, 0x0000, 0x0000, 0x8210, 0x8e73, 0x79ce, 0xdfff, 0xffff, 0xffff, 0xffff, 0xffff, 0xffff, 0xffff, 0xffff, 0xffff, 0xffff, 0xffff, 
  0xffff, 0xffff, 0xffff, 0xffff, 0xffff, 0xffff, 0xffff, 0xffff, 0xffff, 0x9ef7, 0xb294, 0x4529, 0x0000, 0x0000, 0x0000, 0x0000, 0x0000, 0x0000, 0x0000, 0x0000, 0x0000, 0x0000, 0x0000, 0x0000, 0x0000, 0x0000, 0x0000, 0x0000, 0x0000, 0x0000, 0x0000, 0x0000, 0x0000, 0x0000, 0x0000, 0x0000, 0x4529, 0xb294, 0x9ef7, 0xffff, 0xffff, 0xffff, 0xffff, 0xffff, 0xffff, 0xffff, 0xffff, 0xffff, 
  0xffff, 0xffff, 0xffff, 0xffff, 0xffff, 0xffff, 0xffff, 0xffff, 0x5def, 0xae73, 0x4108, 0x0000, 0x0000, 0x0000, 0x0000, 0x0000, 0x0000, 0x0000, 0x0000, 0x0000, 0x0000, 0x0000, 0x0000, 0x0000, 0x0000, 0x0000, 0x0000, 0x0000, 0x0000, 0x0000, 0x0000, 0x0000, 0x0000, 0x0000, 0x0000, 0x0000, 0x0000, 0x4108, 0xae73, 0x7def, 0xffff, 0xffff, 0xffff, 0xffff, 0xffff, 0xffff, 0xffff, 0xffff, 
  0xffff, 0xffff, 0xffff, 0xffff, 0xffff, 0xffff, 0xffff, 0x9ef7, 0xae73, 0x4108, 0x0000, 0x0000, 0x0000, 0x0000, 0x0000, 0x0000, 0x0000, 0x0000, 0x0000, 0x0000, 0x0000, 0x0000, 0x0000, 0x0000, 0x0000, 0x0000, 0x0000, 0x0000, 0x0000, 0x0000, 0x0000, 0x0000, 0x0000, 0x0000, 0x0000, 0x0000, 0x0000, 0x0000, 0x4108, 0xae73, 0x9ef7, 0xffff, 0xffff, 0xffff, 0xffff, 0xffff, 0xffff, 0xffff, 
  0xffff, 0xffff, 0xffff, 0xffff, 0xffff, 0xffff, 0xdfff, 0xb294, 0x4108, 0x0000, 0x0000, 0x0000, 0x0000, 0x0000, 0x0000, 0x0000, 0x0000, 0x0000, 0x0000, 0x0000, 0x0000, 0x0000, 0x0000, 0x0000, 0x0000, 0x0000, 0x0000, 0x0000, 0x0000, 0x0000, 0x0000, 0x0000, 0x0000, 0x0000, 0x0000, 0x0000, 0x0000, 0x0000, 0x0000, 0x4108, 0xb294, 0xdfff, 0xffff, 0xffff, 0xffff, 0xffff, 0xffff, 0xffff, 
  0xffff, 0xffff, 0xffff, 0xffff, 0xffff, 0xffff, 0x79ce, 0x4529, 0x0000, 0x0000, 0x0000, 0x0000, 0x0000, 0x0000, 0x0000, 0x0000, 0x0000, 0x0000, 0x0000, 0x0000, 0x0000, 0x0000, 0x0000, 0x0000, 0x0000, 0x0000, 0x0000, 0x0000, 0x0000, 0x0000, 0x0000, 0x0000, 0x0000, 0x0000, 0x0000, 0x0000, 0x0000, 0x0000, 0x0000, 0x0000, 0x4529, 0x79ce, 0xffff, 0xffff, 0xffff, 0xffff, 0xffff, 0xffff, 
  0xffff, 0xffff, 0xffff, 0xffff, 0xffff, 0xdfff, 0x8e73, 0x0000, 0x0000, 0x0000, 0x0000, 0x0000, 0x0000, 0x0000, 0x0000, 0x0000, 0x0000, 0x0000, 0x0000, 0x0000, 0x0000, 0x0000, 0x0000, 0x0000, 0x0000, 0x0000, 0x0000, 0x0000, 0x0000, 0x0000, 0x0000, 0x0000, 0x0000, 0x0000, 0x0000, 0x0000, 0x0000, 0x0000, 0x0000, 0x0000, 0x0000, 0x8e73, 0xdfff, 0xffff, 0xffff, 0xffff, 0xffff, 0xffff, 
  0xffff, 0xffff, 0xffff, 0xffff, 0xffff, 0xdbde, 0x6108, 0x0000, 0x0000, 0x0000, 0x0000, 0x0000, 0x0000, 0x0000, 0x0000, 0x0000, 0x0000, 0x0000, 0x0000, 0x0000, 0x2008, 0x8020, 0x8020, 0x2008, 0x0000, 0x0000, 0x0000, 0x0000, 0x0000, 0x0000, 0x0000, 0x0000, 0x0000, 0x0000, 0x0000, 0x0000, 0x0000, 0x0000, 0x0000, 0x0000, 0x0000, 0x8210, 0xdbde, 0xffff, 0xffff, 0xffff, 0xffff, 0xffff, 
  0xffff, 0xffff, 0xffff, 0xffff, 0xffff, 0x8e73, 0x0000, 0x0000, 0x0000, 0x0000, 0x0000, 0x0000, 0x0000, 0x0000, 0x0000, 0x0000, 0x0000, 0x0000, 0x0000, 0x2051, 0x20aa, 0x80c2, 0x80ca, 0x40b2, 0xe099, 0xc038, 0x0000, 0x0000, 0x0000, 0x0000, 0x0000, 0x0000, 0x0000, 0x0000, 0x0000, 0x0000, 0x0000, 0x0000, 0x0000, 0x0000, 0x0000, 0x0000, 0xcf7b, 0xffff, 0xffff, 0xffff, 0xffff, 0xffff, 
  0xffff, 0xffff, 0xffff, 0xffff, 0x9ef7, 0x6108, 0x0000, 0x0000, 0x0000, 0x0000, 0x0000, 0x0000, 0x0000, 0x0000, 0x0000, 0x0000, 0x0000, 0x0000, 0xe048, 0xa0da, 0x00fb, 0x00fb, 0x00fb, 0x00fb, 0x00f3, 0xe0e2, 0x20aa, 0x4010, 0x0000, 0x0000, 0x0000, 0x0000, 0x0000, 0x0000, 0x0000, 0x0000, 0x0000, 0x0000, 0x0000, 0x0000, 0x0000, 0x0000, 0x8210, 0x9ef7, 0xffff, 0xffff, 0xffff, 0xffff, 
  0xffff, 0xffff, 0xffff, 0xffff, 0x18c6, 0x0000, 0x0000, 0x0000, 0x0000, 0x0000, 0x0000, 0x0000, 0x0000, 0x0000, 0x0000, 0x0000, 0x0000, 0x4018, 0x00a2, 0x00fb, 0x00fb, 0x00fb, 0x00fb, 0x00fb, 0x00fb, 0x00fb, 0x00fb, 0xc0da, 0x0051, 0x0000, 0x0000, 0x0000, 0x0000, 0x0000, 0x0000, 0x0000, 0x0000, 0x0000, 0x0000, 0x0000, 0x0000, 0x0000, 0x0000, 0x38c6, 0xffff, 0xffff, 0xffff, 0xffff,
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

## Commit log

2024-12-29 UPDATE INFORMATION
    [上侧边按钮1.stl, 上侧边按钮2.stl, 上侧边按钮3.stl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]
2025-01-03 update file
    [BOM_时光磁带（磁带外形的开源MP3播放器）.xlsx, 上侧边按钮1.stl, 上侧边按钮2.stl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]
